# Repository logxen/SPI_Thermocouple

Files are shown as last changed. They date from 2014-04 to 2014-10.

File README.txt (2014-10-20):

This is a simple 1 layer breakout board for the MAX31855 digital thermocouple reader.

Bill of Materials:

1x - 1" x 0.75" single sided copper clad board (pcb)
1x - MAX31855 digital thermocouple ic, 8 pin soic (main ic)
1x - 0.1uF cap, 1206 (power filter)
1x - 10nF cap, 0603 (thermocouple filter)
1x - 1x8 0.1" pin header + 1x4 0.1" pin header
1x - 1x2 0.1" pin header or 2pos 3.5mm screw terminal (thermocouple port: t+, t-)

NOTES:

- the .png file has descriptive layers, the .bmp files are the b/w images for etching, solder mask, silk screen, and solder paste.

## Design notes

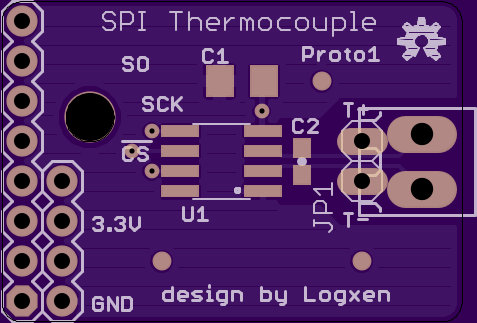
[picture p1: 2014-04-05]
SPI_Thermocouple.png

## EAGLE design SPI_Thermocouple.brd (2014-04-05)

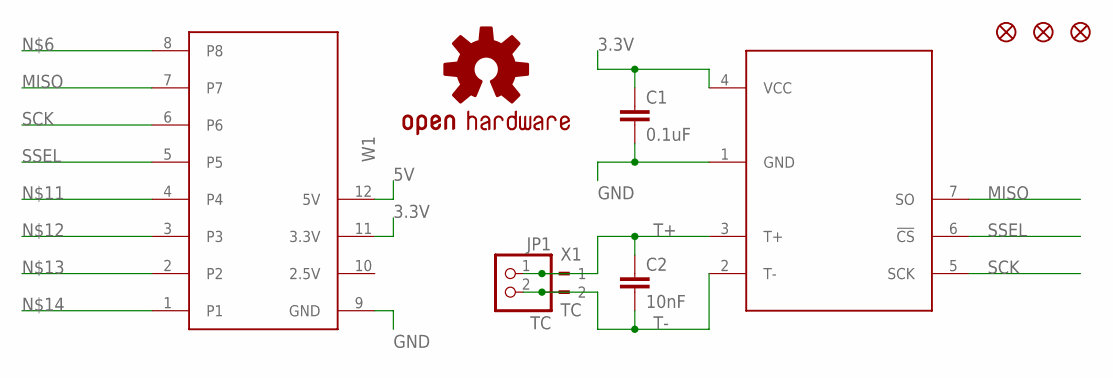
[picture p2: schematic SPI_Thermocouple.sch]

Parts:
C1: 0.1uF; 1206
C2: 10nF; 0603-CAP
FID1, FID2, FID3: FIDUCIAL1X2; FIDUCIAL-1X2
JP1: TC; 1X02
U1: MAX31855; SO08
U$1: OSHW-LOGOS; OSHW-LOGO-S
W1: PAPILIO-WING-8BITS
X1: TC; 180-2

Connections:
3.3V: C1.1, U1.4 (VCC), W1.11 (3.3V)
5V: W1.12 (5V)
GND: C1.2, U1.1 (GND), W1.9 (GND)
MISO: U1.7 (SO), W1.7
SCK: U1.5 (SCK), W1.6
SSEL: U1.6 (!CS), W1.5
T+: C2.1, JP1.1, U1.3 (T+), X1.1
T-: C2.2, JP1.2, U1.2 (T-), X1.2

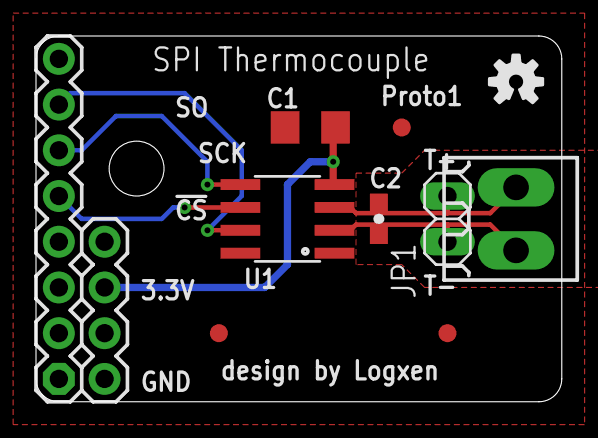
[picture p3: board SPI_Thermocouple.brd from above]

Board: 2 copper layers, 29.2 x 20.3 mm, 10 parts (0 on the bottom side), 7 nets.

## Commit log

2012-07-11 straightened the traces from the thermocouple
    [SPI_Thermocouple.brd]
2014-04-05 upgrade design to a wing
    [SPI_Thermocouple.brd, SPI_Thermocouple.sch]
2014-10-20 removed word "tantalum" from recommended bom

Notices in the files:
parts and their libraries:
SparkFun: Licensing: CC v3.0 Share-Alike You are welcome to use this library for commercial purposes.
